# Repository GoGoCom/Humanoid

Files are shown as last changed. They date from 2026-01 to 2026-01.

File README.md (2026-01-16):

# Humanoid

## Introduction

I built a humanoid robot using the ESP32. For robot control, I used the ESP32's BLE or WiFi functions. I utilized PLEN's motion data to capture the robot's movement data.

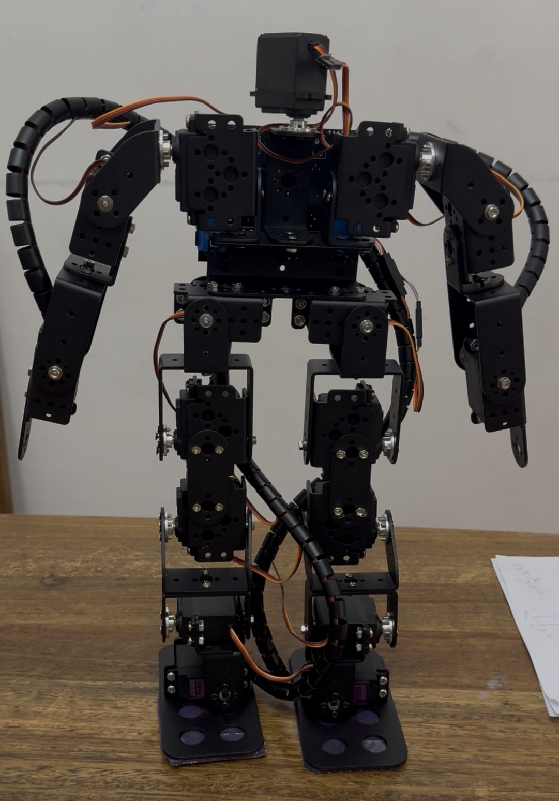
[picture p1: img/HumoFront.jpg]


## Control in webPage using ESP32's BLE

After connecting to the robot via BLE on a web browser on a laptop or PC, you can directly operate the 16 joints or open a data file for a specific continuous movement and make it move. The movement file is borrowed from PLEN-Project( https://github.com/plenprojectcompany ) and can be converted for use, and you can also create movements directly using PLEN's [motion-editor](https://plen.jp/playground/motion-editor/).

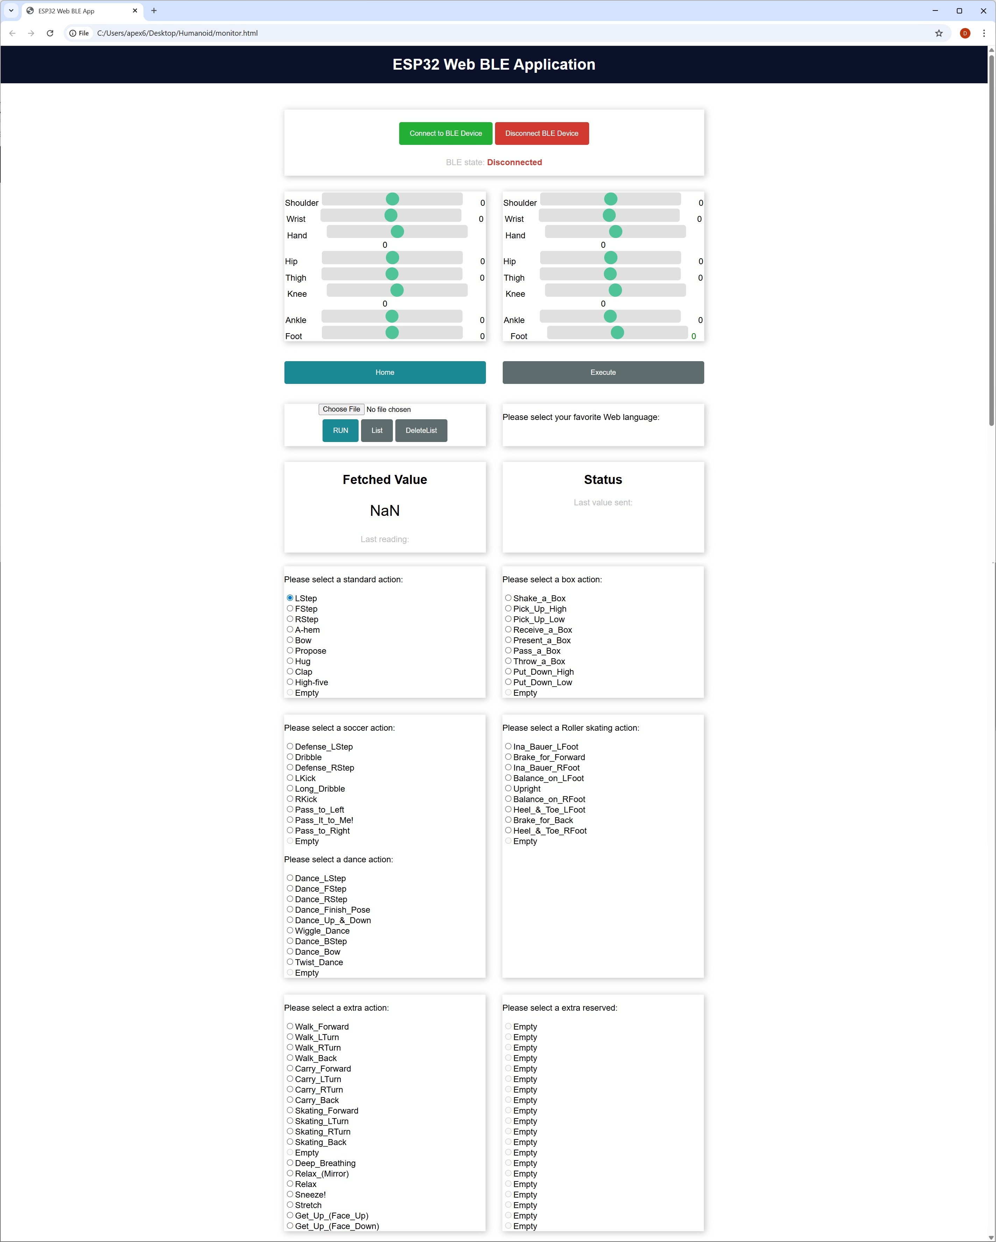
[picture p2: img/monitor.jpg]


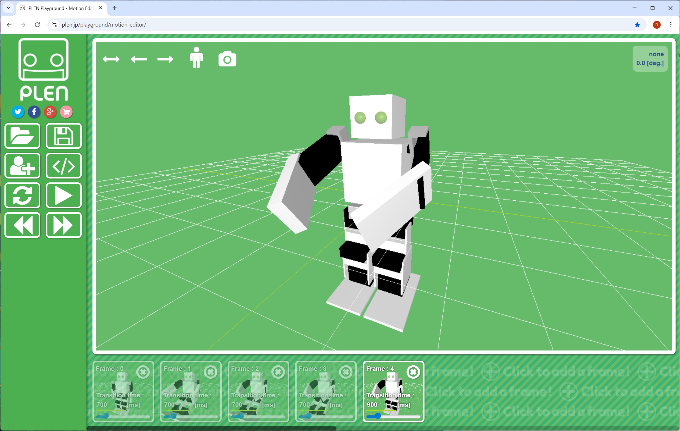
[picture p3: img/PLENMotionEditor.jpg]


## Blynk Tools

[Blynk](https://www.blynk.io/) is an excellent platform for solving IoT problems.It is the most powerful tool when you want to control something on the Internet, whether it is on mobile or PC.
By defining the required streams in the Blynk.Console and connecting them to components, you can exchange data over the network.
You must first sign up on https://blynk.cloud/dashboard/login  before you can use it.

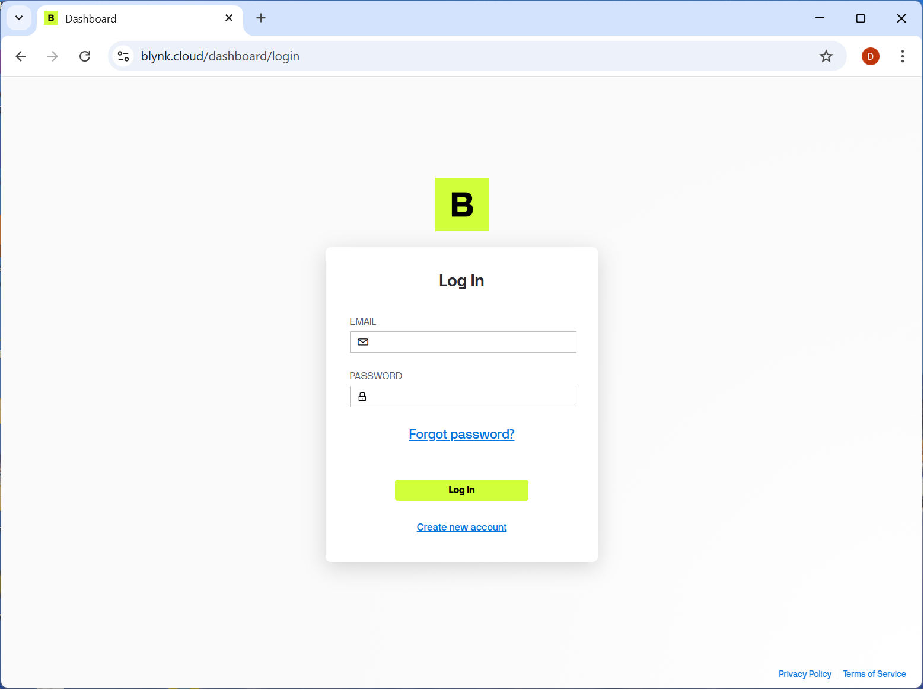
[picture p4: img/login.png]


After defining the device and setting up the development template through the Blynk console, find out the following three values and enter them at the beginning of the source code: BLYNK TEMPLATE ID, BLYNK TEMPLATE_NAME, and BLYNK AUTHTOKEN.


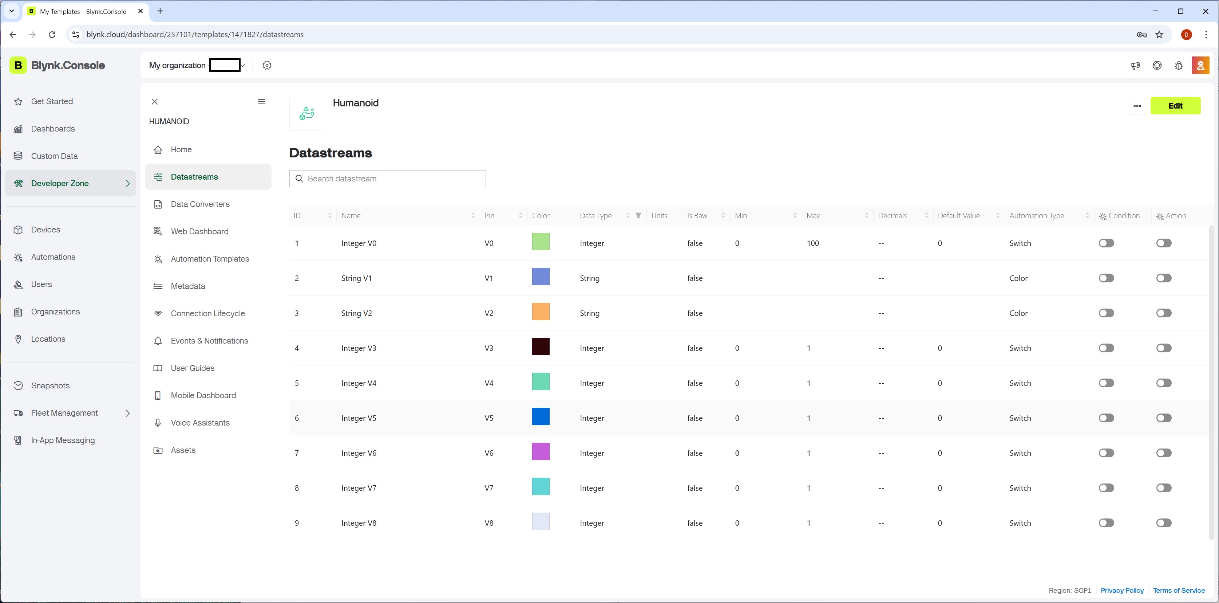
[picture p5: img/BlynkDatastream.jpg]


| define |
|-|
|#define BLYNK_TEMPLATE_ID  "XMgt6fqp4aXvb" |
|#define BLYNK_TEMPLATE_NAME  "Humanoid" |
|#define BLYNK_AUTH_TOKEN  "0f0ffASdldldleefeeXXiCNCvQT3Ff3H" |

### Blynk App / Display

## Library
| Library | version | description |
|-|-|-|
| Blynk | 1.3.2 | IoT |
| ESP8266 and ESP32 OLED driver foe SSSD1306 | 4.6.2 | display |
| ArduinoJson | 7.4.2 | motion datat parsing  |
| ESP32Servo | 3.0.9 | Servo motor  |

## Tool
| Tool | version | description |
|-|-|-|
| Autodesk Eagle | 9.6.2 | hardware |
| Arduino IDE | 2.3.7 | software |

## Acknowledgments

I would like to thank to every one, specially PLEN project team and Rui Santos of RandomNerdTutorials for their contributions.

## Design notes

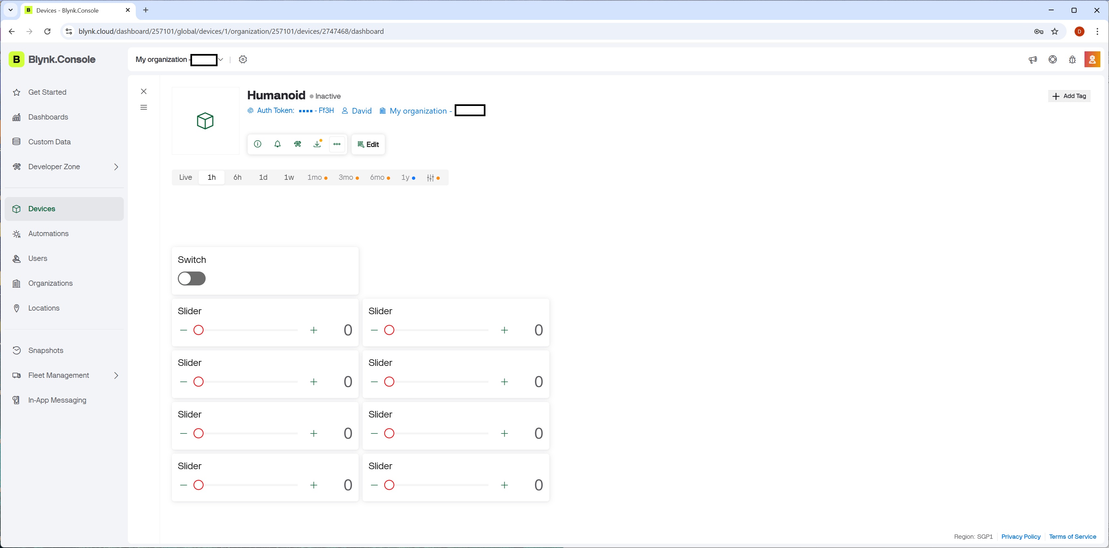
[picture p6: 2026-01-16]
img/device.jpg

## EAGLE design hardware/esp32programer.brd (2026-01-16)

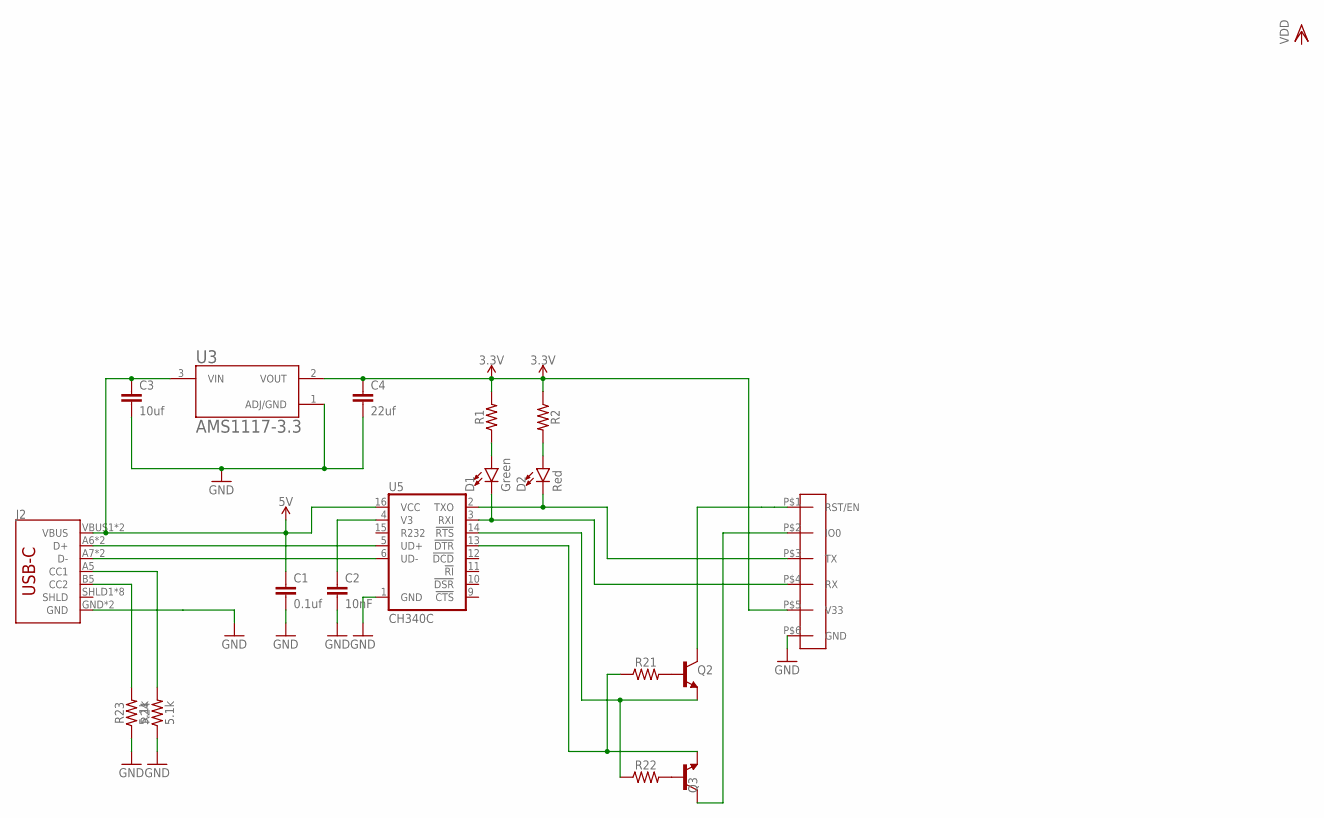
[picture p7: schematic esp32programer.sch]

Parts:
C1: 0.1uf; 0805
C2: 10nF; 0805
C3: 10uf; 0805
C4: 22uf; 0805
D1: Green; LED-0805
D2: Red; LED-0805
J2: USB_C16PIN; USB-C-16P
Q2, Q3: TRANSISTOR_BJT_NPN-SOT-23-BEC; SOT-23
R1, R2, R21, R22: 0805
R23, R24: 5.1k; 0805
U3: AMS1117-3.3; SOT229P700X180-4N
U5: CH340C; SO016
U$6: USBCOUT; 6PINS

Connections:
3.3V: C4.1, R1.2, R2.1, U3.2 (VOUT), U$6.P$5 (V33)
5V: C1.1, C3.1, J2.VBUS1 (VBUS), J2.VBUS2 (VBUS), U3.3 (VIN), U5.16 (VCC)
!DTR: Q3.2 (E), R21.1, U5.13 (!DTR)
CC2: J2.B5 (CC2), R23.2
D+: J2.A6 (D+), J2.B6 (D+), U5.5 (UD+)
D-: J2.A7 (D-), J2.B7 (D-), U5.6 (UD-)
GND: C1.2, C2.2, C3.2, C4.2, J2.GND, J2.GND2 (GND), R23.1, R24.1, U3.1 (ADJ/GND), U5.1 (GND), U$6.P$6 (GND)
unnamed: D1.C, U5.3 (RXI), U$6.P$4 (RX)
unnamed: C2.1, U5.4 (V3)
unnamed: D1.A, R1.1
unnamed: D2.A, R2.2
unnamed: Q2.3 (C), U$6.P$1 (RST/EN)
unnamed: Q3.3 (C), U$6.P$2 (IO0)
unnamed: Q2.2 (E), R22.1, U5.14 (!RTS)
unnamed: Q2.1 (B), R21.2
unnamed: Q3.1 (B), R22.2
unnamed: J2.A5 (CC1), R24.2
RXI: D2.C, U5.2 (TXO), U$6.P$3 (TX)

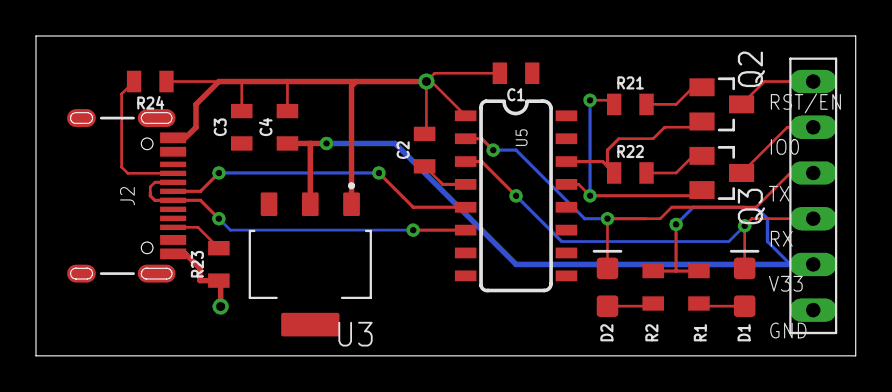
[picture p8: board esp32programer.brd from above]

Board: 2 copper layers, 45.5 x 17.8 mm, 18 parts (0 on the bottom side), 18 nets.

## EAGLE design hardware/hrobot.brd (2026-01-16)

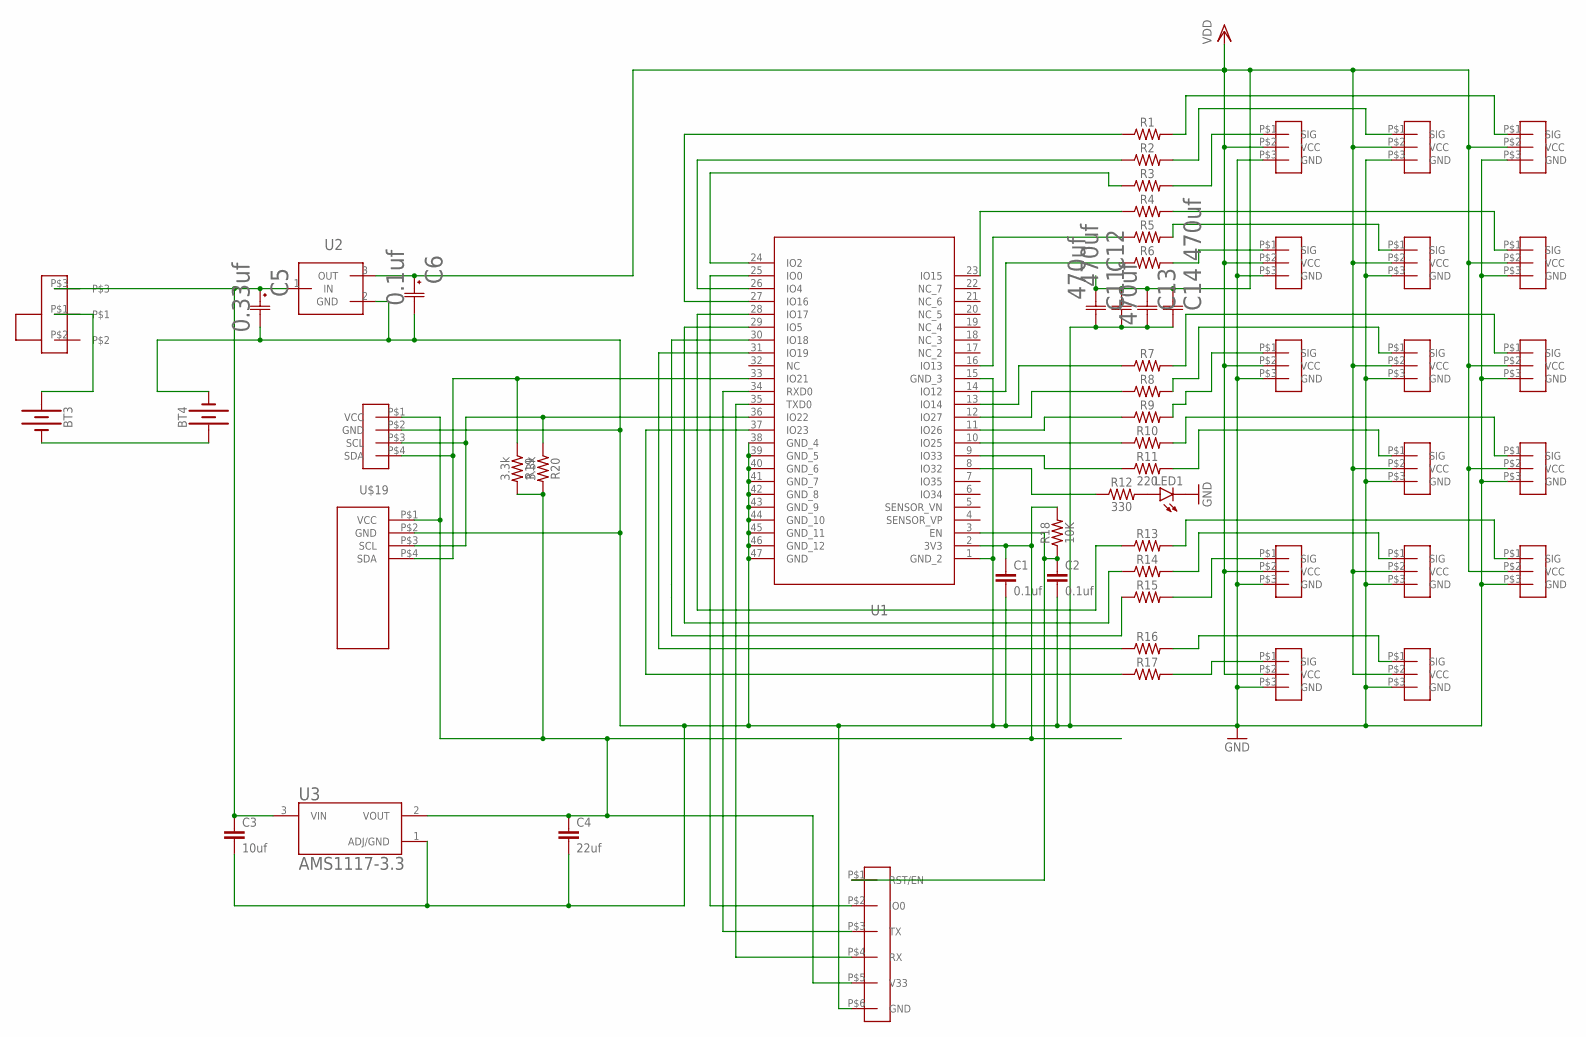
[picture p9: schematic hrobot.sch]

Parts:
BT3, BT4: BATTERY-18650; BATTERY_18650-HOLDER
C1, C2: 0.1uf; 0805
C3: 10uf; 0805
C4: 22uf; 0805
C5: 0.33uf; CAP_UWF_4X5P4_NCH
C6: 0.1uf; CAP_UZE_4X3P9_NCH
C11, C12, C13, C14: 470uf; CAP_J-V_8X10P5_RUB
LED1: LEDSML0805; SML0805
R1, R2, R3, R4, R5, R6, R7, R8, R9, R10, R13, R14, R15, R16, R17: 0805
R11: 220; 0805
R12: 330; 0805
R18: 10K; 0805
R19, R20: 3.3k; 0805
U1: ESP32-WROOM-32E_(4MB)ESP32�WROOM�32E_EXP; ESP32�WROOM�32E_EXP
U2: L7806; L7805FOOT
U3: AMS1117-3.3; SOT229P700X180-4N
U$1, U$2, U$3, U$5, U$6, U$7, U$8, U$9, U$10, U$11, U$12, U$13, U$14, U$15, U$16, U$17: SERVO; 3PINS
U$18: OLEDVCC; OLEPINS
U$19: GYRO; 4PINS
U$20: PWR3PINS
U$23: USBCOUT; 6PINS

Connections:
3V3: C1.1, C4.1, R18.2, R19.2, R20.2, U1.2 (3V3), U3.2 (VOUT), U$18.P$1 (VCC), U$19.P$1 (VCC), U$23.P$5 (V33)
GND: BT4.GND@1 (-), C1.2, C2.2, C3.2, C4.2, C5.2, C6.2, C11.2, C12.2, C13.2, C14.2, LED1.C, U1.1 (GND_2), U1.15 (GND_3), U1.38 (GND_4), U1.39 (GND_5), U1.40 (GND_6), U1.41 (GND_7), U1.42 (GND_8), U1.43 (GND_9), U1.44 (GND_10), U1.45 (GND_11), U1.46 (GND_12), U1.47 (GND), U2.2 (GND), U3.1 (ADJ/GND), U$1.P$3 (GND), U$2.P$3 (GND), U$3.P$3 (GND), U$5.P$3 (GND), U$6.P$3 (GND), U$7.P$3 (GND), U$8.P$3 (GND), U$9.P$3 (GND), U$10.P$3 (GND), U$11.P$3 (GND), U$12.P$3 (GND), U$13.P$3 (GND), U$14.P$3 (GND), U$15.P$3 (GND), U$16.P$3 (GND), U$17.P$3 (GND), U$18.P$2 (GND), U$19.P$2 (GND), U$23.P$6 (GND)
unnamed: BT3.GND@1 (-), BT4.PWR@1 (+)
unnamed: BT3.PWR@1 (+), U$20.P$1
unnamed: R3.2, U$1.P$1 (SIG)
unnamed: R2.2, U$7.P$1 (SIG)
unnamed: R1.2, U$13.P$1 (SIG)
unnamed: R6.2, U$2.P$1 (SIG)
unnamed: R5.2, U$8.P$1 (SIG)
unnamed: R4.2, U$14.P$1 (SIG)
unnamed: R9.2, U$3.P$1 (SIG)
unnamed: R8.2, U$9.P$1 (SIG)
unnamed: R7.2, U$15.P$1 (SIG)
unnamed: LED1.A, R12.2
unnamed: R11.2, U$10.P$1 (SIG)
unnamed: R10.2, U$16.P$1 (SIG)
unnamed: R15.2, U$5.P$1 (SIG)
unnamed: R14.2, U$11.P$1 (SIG)
unnamed: R13.2, U$17.P$1 (SIG)
unnamed: R17.2, U$6.P$1 (SIG)
unnamed: R16.2, U$12.P$1 (SIG)
unnamed: C3.1, C5.1, U2.1 (IN), U3.3 (VIN), U$20.P$3
unnamed: R16.1, U1.31 (IO19)
unnamed: R1.1, U1.27 (IO16)
unnamed: R2.1, U1.26 (IO4)
unnamed: C2.1, R18.1, U1.3 (EN), U$23.P$1 (RST/EN)
unnamed: R4.1, U1.23 (IO15)
unnamed: R5.1, U1.16 (IO13)
unnamed: R6.1, U1.14 (IO12)
unnamed: R17.1, U1.37 (IO23)
unnamed: R14.1, U1.29 (IO5)
unnamed: R15.1, U1.30 (IO18)
unnamed: R13.1, U1.28 (IO17)
unnamed: R19.1, U1.33 (IO21), U$18.P$4 (SDA), U$19.P$4 (SDA)
unnamed: R11.1, U1.9 (IO33)
unnamed: R10.1, U1.10 (IO25)
unnamed: R9.1, U1.11 (IO26)
unnamed: R8.1, U1.12 (IO27)
unnamed: R7.1, U1.13 (IO14)
unnamed: R20.1, U1.36 (IO22), U$18.P$3 (SCL), U$19.P$3 (SCL)
unnamed: R12.1, U1.8 (IO32)
unnamed: R3.1, U1.24 (IO2)
unnamed: U1.35 (TXD0), U$23.P$4 (RX)
unnamed: U1.34 (RXD0), U$23.P$3 (TX)
unnamed: U1.25 (IO0), U$23.P$2 (IO0)
VDD: C6.1, C11.1, C12.1, C13.1, C14.1, U2.3 (OUT), U$1.P$2 (VCC), U$2.P$2 (VCC), U$3.P$2 (VCC), U$5.P$2 (VCC), U$6.P$2 (VCC), U$7.P$2 (VCC), U$8.P$2 (VCC), U$9.P$2 (VCC), U$10.P$2 (VCC), U$11.P$2 (VCC), U$12.P$2 (VCC), U$13.P$2 (VCC), U$14.P$2 (VCC), U$15.P$2 (VCC), U$16.P$2 (VCC), U$17.P$2 (VCC)

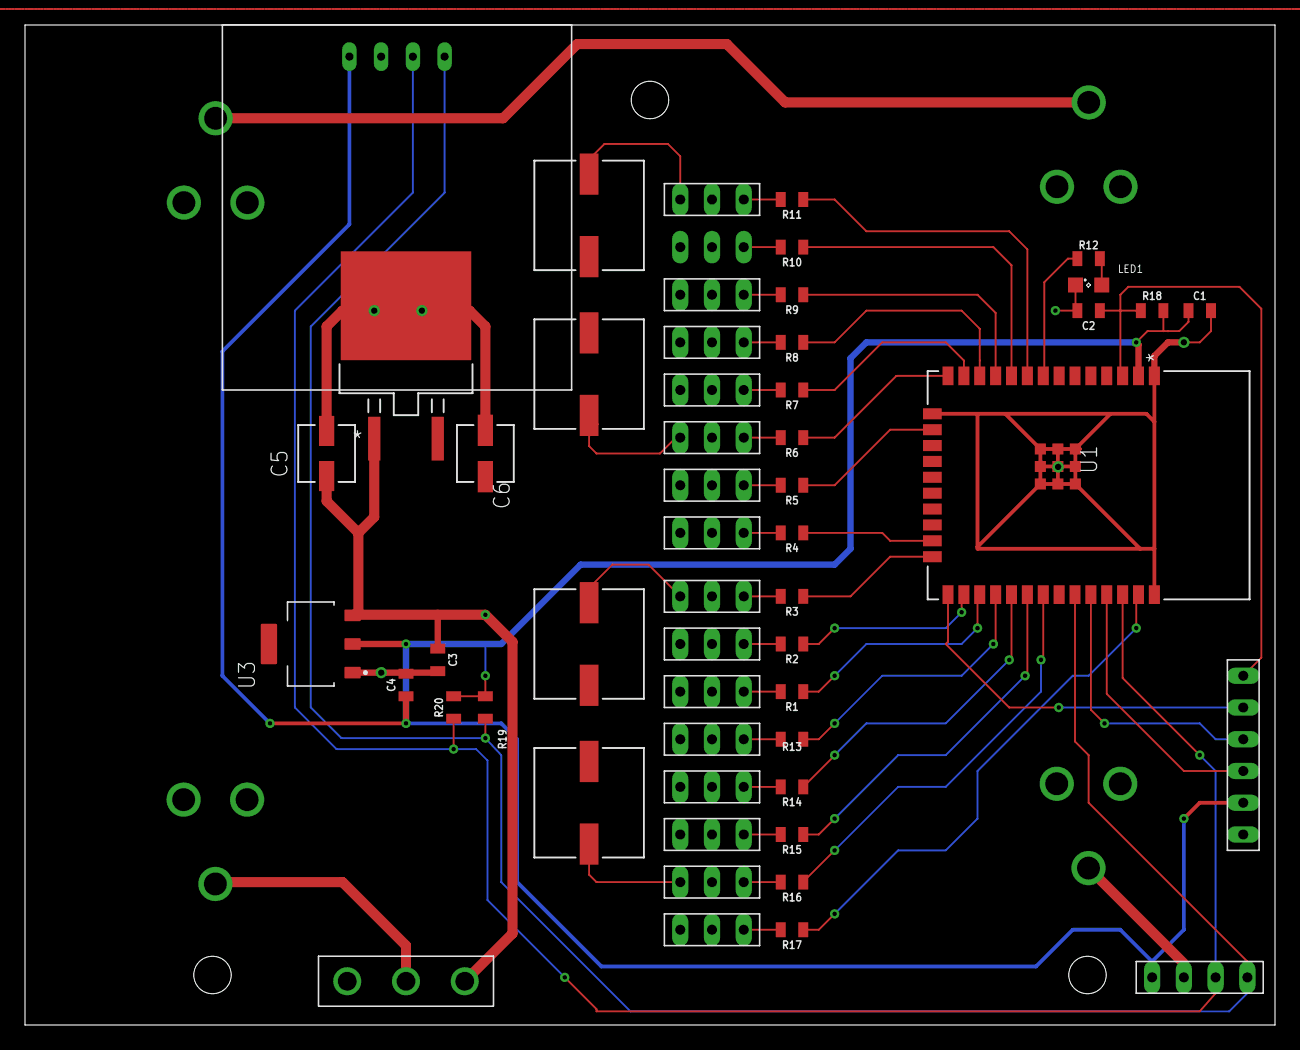
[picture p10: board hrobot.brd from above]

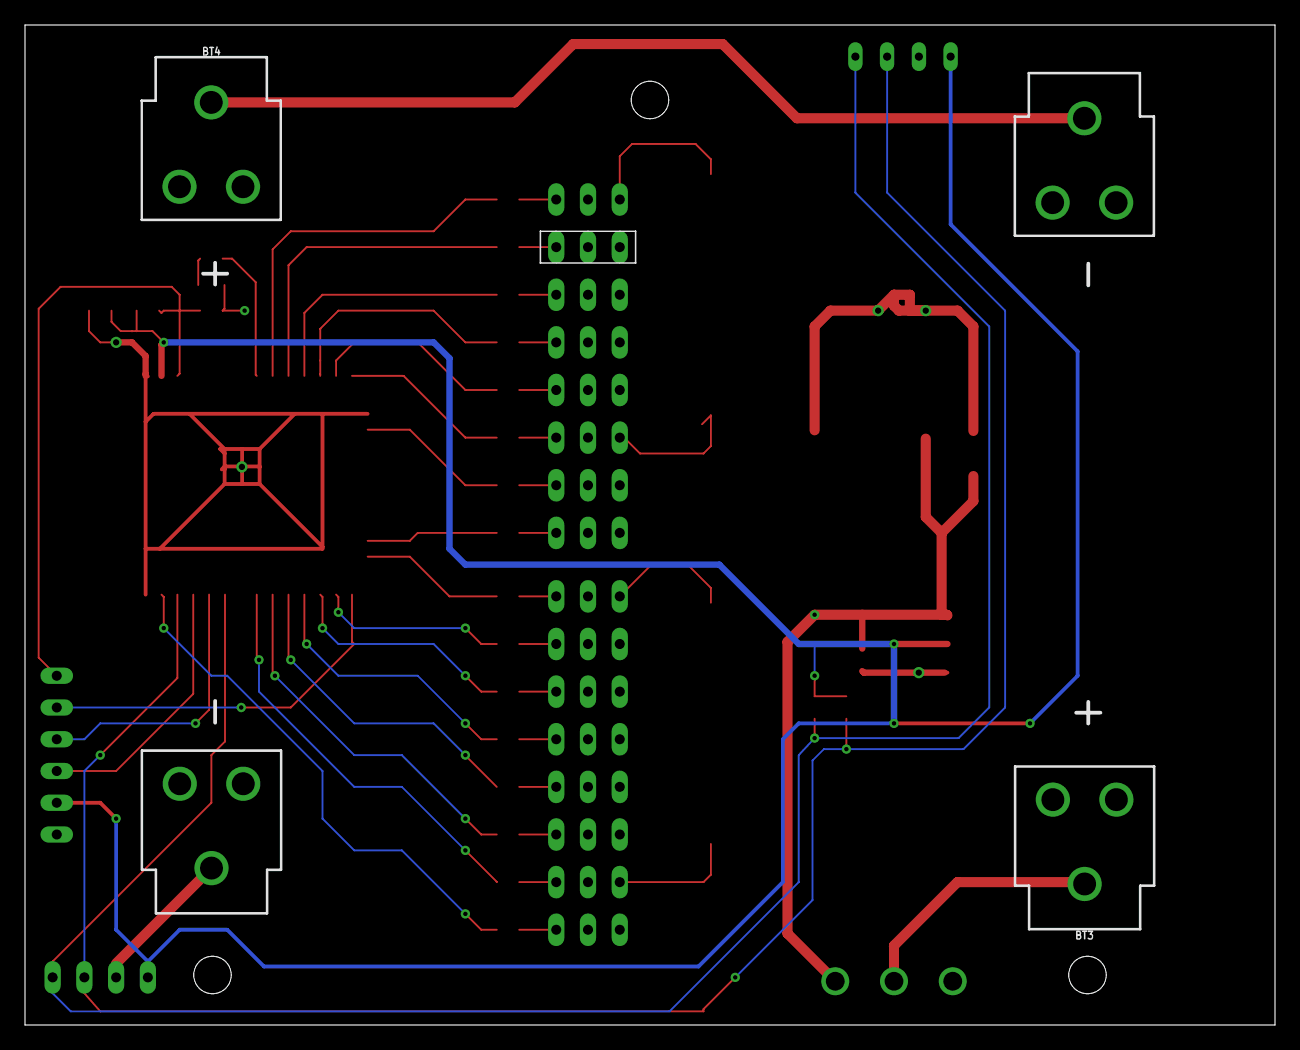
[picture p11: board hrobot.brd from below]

Board: 2 copper layers, 100.0 x 80.0 mm, 56 parts (3 on the bottom side), 46 nets.

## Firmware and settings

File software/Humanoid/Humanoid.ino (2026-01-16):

/**

   Create by David Lee/ Gogocom
   January/2025
   
   The MIT License (MIT)

*/
#define BLYNK_PRINT Serial

/* Fill in information from Blynk Device Info here */
#define BLYNK_TEMPLATE_ID "TMPL6hhhhhh" // your own
#define BLYNK_TEMPLATE_NAME "Humanoid"
#define BLYNK_AUTH_TOKEN "fLaAtyhlrthklrtkhlrtkhrtl;khrl;" // your own

//deserialize a JSON document with ArduinoJson.
#include <ArduinoJson.h>
#include <string.h>

// For a WiFi connection and Blynk
#include <WiFi.h>
#include <WiFiClient.h>
#include <BlynkSimpleEsp32.h>

#include <BLEDevice.h>
#include <BLEServer.h>
#include <BLEUtils.h>
#include <BLE2902.h>

// Include the correct display library
#include <ESP32Servo.h>

// For a connection via I2C using the Arduino Wire include:
#include <Wire.h>               // Only needed for Arduino 1.6.5 and earlier
#include "SSD1306Wire.h"        // legacy: #include "SSD1306.h"

// SPIFFFS for writing or reading a temporary json file.
#include <FS.h>
#include <SPIFFS.h>

/* You only need to format SPIFFS the first time you run a
   test or else use the SPIFFS plugin to create a partition
   https://github.com/me-no-dev/arduino-esp32fs-plugin */
#define FORMAT_SPIFFS_IF_FAILED true



// Optionally include custom images
#include "images.h"

//#define debug

#define LED_ON   HIGH
#define LED_OFF  LOW

#define BLYNK_RED       "#D3435C"
#define BLYNK_GREEN     "#23C48E"
#define BLYNK_DARK_BLUE "#5F7CD8"
#define BLYNK_BLUE      "#04C0F8"
#define BLYNK_WHITE     "#FFFFFF"
#define BLYNK_YELLOW    "#ED9D00"

#define TEST      1
#define WAKING    0
#define BiKiBiKi  1

#define ActionMax 20
#define FramesMax 64

// Your WiFi credentials.
// Set password to "" for open networks.
char* ssid         = "COREANHOUSE";
char* password     = "COREAN000";


enum {
  Right, Left, BothS, BothC
};

enum {
  Shoulder, Elbow, Wrist, Hip, Thigh, Knee, Ankle, Foot 
} ;



//Head 32
struct act {
  int mode ;
  int which;
  int degree;
} ;

struct BehaviorLoop {
    int first;
    int last;
    int count;
};

struct BehaviorBody {
    int index;
    int musle[2][8];
    int tdelay;
};

struct Behavior {
  int count;
  struct BehaviorBody actions[ActionMax];
  int Number;
  const char *Name;
};

struct BehaviorExtend {
  int count;
  struct BehaviorLoop Loop[5];
  struct BehaviorBody actions[ActionMax];
  int Number;
  const char *Name;
};

struct body {
  int pin;
  int offset;
  int initial;
  int min;
  int max;
} RobotBody[2][8] = {
  //Shoulder,               Elbow, (+35, -35)        Wrist,                Hip,                 Thigh,  (-10,+10)        Knee,(+45, -45)        Ankle,                Foot 
//   { { 2, -1, 0,-90, +90 },{ 4, +1,  0, -125, +55 },{16, +1, 0,-90, +90 },{17, +1, 0,-90, +90 },{ 5, +1, 0, -85, +95},{18, -1, 0, -135, +45 },{19, -1, 0, -85, +95 },{23, +1, 0,-90, +90 }},  // right
//   { {33, -1, 0,-90, +90 },{25, +1,  0, -55, +125 },{26, +1, 0,-90, +90 },{27, +1, 0,-90, +90 },{14, +1, 0,-95, +85 },{12, -1, 0, -45, +135 },{13, -1, 0, -95, +85 },{15, +1, 0,-90, +90 }}   // left
   { { 2, -1, 0,-90, +90 },{ 4, +1,  0, -125, +55 },{16, +1, 0,-90, +90 },{17, +1, 0,-90, +90 },{ 5, +1, 0, -45, +135},{18, -1, 0, -58, +122 },{19, -1, 0, -45, +135 },{23, +1, 0,-90, +90 }},  // right
   { {33, -1, 0,-90, +90 },{25, +1,  0, -55, +125 },{26, +1, 0,-90, +90 },{27, +1, 0,-90, +90 },{14, +1, 0,-135, +45 },{12, -1, 0, -122, +58 },{13, -1, 0, -135, +45 },{15, +1, 0,-90, +90 }}   // left
};


  // JSON input string for conversion
const char *jsonDevice = "  {      \
    \"right_thigh_yaw\"      : [0,-1], \
    \"right_shoulder_pitch\" : [0, 0], \
    \"right_shoulder_roll\"  : [0, 1], \
    \"right_elbow_roll\"     : [0, 2], \
    \"right_thigh_roll\"     : [0, 3], \
    \"right_thigh_pitch\"    : [0, 4], \
    \"right_knee_pitch\"     : [0, 5], \
    \"right_foot_pitch\"     : [0, 6], \
    \"right_foot_roll\"      : [0, 7], \
     \"left_thigh_yaw\"      : [1,-1], \
    \"left_shoulder_pitch\"  : [1, 0], \
    \"left_shoulder_roll\"   : [1, 1], \
    \"left_elbow_roll\"      : [1, 2], \
    \"left_thigh_roll\"      : [1, 3], \
    \"left_thigh_pitch\"     : [1, 4], \
    \"left_knee_pitch\"      : [1, 5], \
    \"left_foot_pitch\"      : [1, 6], \
    \"left_foot_roll\"       : [1, 7]  \
    }";

struct BehaviorExtend Frame =
 {
  0,
  {
    {0,0,0},
    {0,0,0}
  },
  {
    { 
      0,
      {
        {0,0,0,0,0,0,0,0 },
        {0,0,0,0,0,0,0,0 }
      },
      0
    },
    {
      1,
      {
        {0,0,0,0,0,0,0,0 },
        {0,0,0,0,0,0,0,0 }
      },
      0
    }
  },
  100,
  "anme"
};

const struct Behavior Frames[] = {
{
 11,
 { {
     0,
     {
       {0,0,0,0,0,0,0,0 },
       {0,0,0,0,0,0,0,0 }
     },
     100
   },{
     1,
     {
       {-114,0,0,50,0,0,0,-157 },
       {-83,-110,0,-64,0,0,0,-159 }
     },
     380
   },{
     2,
     {
       {199,110,142,50,0,0,0,-165 },
       {282,-110,86,-134,268,-918,-266,-129 }
     },
     360
   },{
     3,
     {
       {199,150,142,50,0,0,24,-155 },
       {282,-110,86,-134,-380,-788,-266,-129 }
     },
     340
   },{
     4,
     {
       {199,150,142,50,0,0,24,-145 },
       {282,-110,86,-134,-380,-788,-266,-129 }
     },
     340
   },{
     5,
     {
       {-349,92,55,50,-55,423,285,-175 },
       {-474,-110,-74,-134,346,-866,21,-129 }
     },
     140
   },{
     6,
     {
       {-610,22,52,65,4,423,285,-162 },
       {-422,-190,-132,-128,711,-240,-214,10 }
     },
     180
   },{
     7,
     {
       {-610,22,52,65,4,423,285,-158 },
       {-422,-190,-132,-128,711,-240,-214,10 }
     },
     480
   },{
     8,
     {
       {-377,148,237,50,-229,579,322,-158 },
       {-422,-190,-132,-83,466,-853,252,10 }
     },
     480
   },{
     9,
     {
       {199,148,142,50,-57,0,0,-135 },
       {282,-42,125,-51,268,-475,-110,-129 }
     },
     540
   },{
     10,
     {
       {0,0,0,0,0,0,0,0 },
       {0,0,0,0,0,0,0,0 }
     },
     360
   },
 },
 23,
 "LKick" ,
},{
 16,
 { {
     0,
     {
       {0,0,0,0,0,0,0,0 },
       {0,0,0,0,0,0,0,0 }
     },
     100
   },{
     1,
     {
       {0,-9,-21,20,0,0,0,-10 },
       {-10,9,21,30,0,0,0,0 }
     },
     200
   },{
     2,
     {
       {0,21,-31,150,-268,605,294,140 },
       {0,-21,31,120,-130,0,-110,140 }
     },
     200
   },{
     3,
     {
       {185,51,-29,140,-535,512,27,102 },
       {142,-31,19,140,-120,0,-130,105 }
     },
     110
   },{
     4,
     {
       {185,-9,-39,-50,-325,432,177,-58 },
       {142,-41,29,-50,-240,-90,-360,-85 }
     },
     130
   },{
     5,
     {
       {0,21,31,-120,130,0,110,-140 },
       {0,-21,-31,-150,268,-605,-294,-140 }
     },
     180
   },{
     6,
     {
       {-142,31,19,-140,120,0,130,-105 },
       {-185,-51,-29,-140,535,-512,-27,-102 }
     },
     100
   },{
     7,
     {
       {-142,41,29,50,240,90,360,85 },
       {-185,9,-39,50,325,-432,-177,58 }
     },
     120
   },{
     8,
     {
       {0,21,-31,150,-268,605,294,140 },
       {0,-21,31,120,-130,0,-110,140 }
     },
     210
   },{
     9,
     {
       {185,51,-29,140,-535,512,27,102 },
       {142,-31,19,140,-120,0,-130,105 }
     },
     130
   },{
     10,
     {
       {185,-9,-39,-50,-325,432,177,-58 },
       {142,-41,29,-50,-240,-90,-360,-85 }
     },
     150
   },{
     11,
     {
       {0,21,31,-120,130,0,110,-140 },
       {0,-21,-31,-150,268,-605,-294,-140 }
     },
     240
   },{
     12,
     {
       {-142,31,19,-140,120,0,130,-105 },
       {-185,-51,-29,-140,535,-512,-27,-102 }
     },
     160
   },{
     13,
     {
       {-142,41,29,50,240,90,360,85 },
       {-185,9,-39,50,325,-432,-177,58 }
     },
     180
   },{
     14,
     {
       {0,1,-79,80,-108,245,84,80 },
       {0,-21,-31,40,0,0,0,80 }
     },
     180
   },{
     15,
     {
       {0,0,0,0,0,0,0,0 },
       {0,0,0,0,0,0,0,0 }
     },
     240
   },
 },
 24,
 "Long Dribble" ,
},{
 11,
 { {
     0,
     {
       {0,0,0,0,0,0,0,0 },
       {0,0,0,0,0,0,0,0 }
     },
     100
   },{
     1,
     {
       {83,110,0,64,0,0,0,159 },
       {114,0,0,0,0,0,0,157 }
     },
     380
   },{
     2,
     {
       {-282,110,-86,134,-268,918,266,129 },
       {-199,-110,-142,0,0,0,0,165 }
     },
     360
   },{
     3,
     {
       {-282,110,-86,134,380,788,266,129 },
       {-199,-150,-142,0,0,0,-24,155 }
     },
     340
   },{
     4,
     {
       {-282,110,-86,134,380,788,266,129 },
       {-199,-150,-142,0,0,0,-24,145 }
     },
     340
   },{
     5,
     {
       {474,110,74,134,-346,866,-21,129 },
       {349,-92,-55,0,-4,-423,-285,175 }
     },
     140
   },{
     6,
     {
       {422,190,132,128,-711,240,214,-10 },
       {610,-22,-52,0,0,-579,-322,162 }
     },
     180
   },{
     7,
     {
       {422,190,132,128,-711,240,214,-10 },
       {610,-22,-52,0,0,-579,-322,158 }
     },
     480
   },{
     8,
     {
       {422,190,132,83,-466,853,-252,-10 },
       {377,-148,-237,0,229,-579,-322,158 }
     },
     480
   },{
     9,
     {
       {-282,42,-125,51,-268,475,110,129 },
       {-199,-148,-142,0,57,0,0,135 }
     },
     540
   },{
     10,
     {
       {0,0,0,0,0,0,0,0 },
       {0,0,0,0,0,0,0,0 }
     },
     360
   },
 },
 25,
 "RKick" ,
},{
 15,
 { {
     0,
     {
       {0,0,0,0,0,0,0,0 },
       {0,0,0,0,0,0,0,0 }
     },
     100
   },{
     1,
     {
       {0,322,557,0,0,0,0,0 },
       {0,-322,-557,0,0,0,0,0 }
     },
     200
   },{
     2,
     {
       {0,322,557,20,0,0,0,60 },
       {0,-322,-557,20,0,0,0,60 }
     },
     200
   },{
     3,
     {
       {0,322,557,35,-181,354,157,37 },
       {0,-322,-557,39,0,0,13,76 }
     },
     200
   },{
     4,
     {
       {0,322,557,165,-111,214,87,127 },
       {0,-322,-557,39,0,0,13,46 }
     },
     200
   },{
     5,
     {
       {0,322,557,159,-178,302,155,97 },
       {0,-322,-557,19,90,-127,-50,-60 }
     },
     200
   },{
     6,
     {
       {0,322,557,38,-90,127,50,60 },
       {0,-322,-557,-38,90,-127,-50,-60 }
     },
     200
   },{
     7,
     {
       {0,627,557,38,-522,948,500,60 },
       {0,-627,-557,-38,522,-866,-435,-60 }
     },
     400
   },{
     8,
     {
       {0,322,557,38,-90,127,50,60 },
       {0,-322,-557,-38,90,-127,-50,-60 }
     },
     400
   },{
     9,
     {
       {0,628,557,38,-522,948,500,60 },
       {0,-627,-557,-38,522,-866,-435,-60 }
     },
     400
   },{
     10,
     {
       {0,322,557,38,-90,127,50,60 },
       {0,-322,-557,-38,90,-127,-50,-60 }
     },
     400
   },{
     11,
     {
       {0,322,557,-85,-86,127,50,-80 },
       {0,-322,-557,-182,50,-16,45,-204 }
     },
     200
   },{
     12,
     {
       {0,322,557,-39,-86,127,50,-57 },
       {0,-322,-557,-39,214,-408,-194,-97 }
     },
     200
   },{
     13,
     {
       {0,322,557,0,0,0,0,0 },
       {0,-322,-557,0,0,0,0,0 }
     },
     200
   },{
     14,
     {
       {0,0,0,0,0,0,0,0 },
       {0,0,0,0,0,0,0,0 }
     },
     200
   },
 },
 32,
 "Dance RStep" ,
},{
 7,
 { {
     0,
     {
       {0,0,0,0,0,0,0,0 },
       {0,0,0,0,0,0,0,0 }
     },
     100
   },{
     1,
     {
       {0,322,557,0,0,0,0,0 },
       {0,-322,-557,0,0,0,0,0 }
     },
     600
   },{
     2,
     {
       {0,322,557,0,0,0,0,0 },
       {0,-322,-557,0,0,0,0,0 }
     },
     600
   },{
     3,
     {
       {0,322,557,7,0,0,0,-24 },
       {0,-774,647,2,0,0,0,-5 }
     },
     1000
   },{
     4,
     {
       {0,322,557,216,0,0,0,194 },
       {0,-643,569,196,0,0,0,189 }
     },
     1000
   },{
     5,
     {
       {0,322,557,216,0,0,0,194 },
       {0,-643,569,196,0,0,0,189 }
     },
     1600
   },{
     6,
     {
       {0,0,0,0,0,0,0,0 },
       {0,0,0,0,0,0,0,0 }
     },
     1000
   },
 },
 33,
 "Dance Finish Pose" ,
},{
 9,
 { {
     0,
     {
       {0,0,0,0,0,0,0,0 },
       {0,0,0,0,0,0,0,0 }
     },
     100
   },{
     1,
     {
       {0,322,557,0,-217,620,403,0 },
       {0,-322,-557,0,217,-620,-403,0 }
     },
     600
   },{
     2,
     {
       {0,0,0,0,0,0,0,0 },
       {0,0,0,0,0,0,0,0 }
     },
     600
   },{
     3,
     {
       {0,322,557,0,-217,620,403,0 },
       {0,-322,-557,0,217,-620,-403,0 }
     },
     600
   },{
     4,
     {
       {0,0,0,0,0,0,0,0 },
       {0,0,0,0,0,0,0,0 }
     },
     600
   },{
     5,
     {
       {636,322,557,0,-217,620,403,0 },
       {569,-322,-557,0,217,-620,-403,0 }
     },
     600
   },{
     6,
     {
       {0,0,0,0,0,0,0,0 },
       {0,0,0,0,0,0,0,0 }
     },
     600
   },{
     7,
     {
       {-569,322,557,0,-217,620,403,0 },
       {-636,-322,-557,0,217,-620,-403,0 }
     },
     600
   },{
     8,
     {
       {0,0,0,0,0,0,0,0 },
       {0,0,0,0,0,0,0,0 }
     },
     600
   },
 },
 34,
 "Dance Up & Down" ,
},{
 20,
 { {
     0,
     {
       {0,0,0,0,0,0,0,0 },
       {0,0,0,0,0,0,0,0 }
     },
     100
   },{
     1,
     {
       {0,322,557,-116,0,0,0,-94 },
       {0,-322,-557,-116,0,0,0,-94 }
     },
     600
   },{
     2,
     {
       {0,322,557,116,0,0,0,94 },
       {0,-322,-557,116,0,0,0,94 }
     },
     600
   },{
     3,
     {
       {0,322,557,-116,0,0,0,-94 },
       {0,-322,-557,-116,0,0,0,-94 }
     },
     600
   },{
     4,
     {
       {0,322,557,116,0,0,0,94 },
       {0,-322,-557,116,0,0,0,94 }
     },
     600
   },{
     5,
     {
       {0,322,557,-116,0,0,0,-94 },
       {0,-322,-557,-116,0,0,0,-94 }
     },
     600
   },{
     6,
     {
       {0,322,557,116,0,0,0,94 },
       {0,-322,-557,116,0,0,0,94 }
     },
     600
   },{
     7,
     {
       {0,322,557,-116,0,0,0,-94 },
       {0,-322,-557,-116,0,0,0,-94 }
     },
     600
   },{
     8,
     {
       {0,322,557,116,0,0,0,94 },
       {0,-322,-557,116,0,0,0,94 }
     },
     600
   },{
     9,
     {
       {0,322,557,-116,0,0,0,-94 },
       {0,-322,-557,-116,0,0,0,-94 }
     },
     600
   },{
     10,
     {
       {0,322,557,116,0,0,0,94 },
       {0,-643,569,116,0,0,0,94 }
     },
     600
   },{
     11,
     {
       {0,322,557,-99,157,0,131,-84 },
       {0,-322,-557,-109,-177,0,-120,-103 }
     },
     580
   },{
     12,
     {
       {0,322,557,-99,-139,0,-95,-84 },
       {0,-322,-557,-109,119,0,81,-81 }
     },
     580
   },{
     13,
     {
       {0,322,557,110,-139,0,-95,125 },
       {0,-322,-557,114,119,0,81,101 }
     },
     580
   },{
     14,
     {
       {0,322,557,110,157,0,131,125 },
       {0,-322,-557,114,-177,0,-120,101 }
     },
     580
   },{
     15,
     {
       {0,324,-56,-99,157,0,131,-84 },
       {0,-747,308,-109,-177,0,-120,-103 }
     },
     580
   },{
     16,
     {
       {0,768,-317,-99,-139,0,-95,-84 },
       {0,-278,99,-109,119,0,81,-81 }
     },
     580
   },{
     17,
     {
       {0,324,-56,110,-139,0,-95,125 },
       {0,-747,308,114,119,0,81,101 }
     },
     580
   },{
     18,
     {
       {0,768,-317,110,157,0,131,125 },
       {0,-278,99,114,-177,0,-120,101 }
     },
     580
   },{
     19,
     {
       {0,0,0,0,0,0,0,0 },
       {0,0,0,0,0,0,0,0 }
     },
     600
   },
 },
 35,
 "Wiggle Dance" ,
},{
 12,
 { {
     0,
     {
       {0,0,0,0,0,0,0,0 },
       {0,0,0,0,0,0,0,0 }
     },
     100
   },{
     1,
     {
       {0,0,0,0,0,0,0,0 },
       {0,0,0,0,0,0,0,0 }
     },
     440
   },{
     2,
     {
       {0,0,0,-100,0,0,0,-100 },
       {0,0,0,-84,152,-388,-199,-84 }
     },
     220
   },{
     3,
     {
       {147,0,0,-100,-126,128,27,-100 },
       {202,0,0,-84,-100,-116,-223,-84 }
     },
     400
   },{
     4,
     {
       {147,628,556,-100,-555,882,359,-100 },
       {202,-625,-555,-84,562,-939,-415,-84 }
     },
     400
   },{
     5,
     {
       {147,0,0,-100,-126,128,27,-100 },
       {202,0,0,-84,-11,-116,-152,-84 }
     },
     400
   },{
     6,
     {
       {147,627,558,-100,-555,882,359,-100 },
       {202,-625,-557,-84,562,-939,-415,-84 }
     },
     400
   },{
     7,
     {
       {147,0,0,-100,-126,128,27,-100 },
       {202,0,0,-84,-100,-116,-223,-84 }
     },
     400
   },{
     8,
     {
       {69,0,0,100,-373,340,-17,122 },
       {72,0,0,84,0,0,0,84 }
     },
     200
   },{
     9,
     {
       {0,0,0,100,-102,298,159,150 },
       {0,0,0,84,0,0,0,94 }
     },
     200
   },{
     10,
     {
       {0,0,0,100,0,0,0,100 },
       {0,0,0,84,0,0,0,84 }
     },
     200
   },{
     11,
     {
       {0,0,0,0,0,0,0,0 },
       {0,0,0,0,0,0,0,0 }
     },
     440
   },
 },
 36,
 "Dance BStep" ,
},{
 4,
 { {
     0,
     {
       {0,0,0,0,0,0,0,0 },
       {0,0,0,0,0,0,0,0 }
     },
     100
   },{
     1,
     {
       {-517,177,516,0,-403,0,-130,0 },
       {-560,-136,-516,0,403,0,130,0 }
     },
     1000
   },{
     2,
     {
       {-517,177,516,0,-403,0,-130,0 },
       {-560,-136,-516,0,403,0,130,0 }
     },
     3060
   },{
     3,
     {
       {0,0,0,0,0,0,0,0 },
       {0,0,0,0,0,0,0,0 }
     },
     1140
   },
 },
 37,
 "Dance Bow" ,
},{
 10,
 { {
     0,
     {
       {0,0,0,0,0,0,0,0 },
       {0,0,0,0,0,0,0,0 }
     },
     100
   },{
     1,
     {
       {0,322,557,0,-217,620,403,0 },
       {0,-322,-557,0,217,-620,-403,0 }
     },
     600
   },{
     2,
     {
       {0,0,0,0,0,0,0,0 },
       {0,0,0,0,0,0,0,0 }
     },
     600
   },{
     3,
     {
       {0,322,557,0,-217,620,403,0 },
       {0,-322,-557,0,217,-620,-403,0 }
     },
     600
   },{
     4,
     {
       {0,0,0,0,0,0,0,0 },
       {0,0,0,0,0,0,0,0 }
     },
     600
   },{
     5,
     {
       {-374,92,-4,0,-217,620,403,0 },
       {797,-92,-4,0,217,-620,-403,0 }
     },
     600
   },{
     6,
     {
       {-795,95,4,0,-217,620,403,0 },
       {371,-89,4,0,217,-620,-403,0 }
     },
     600
   },{
     7,
     {
       {-374,92,-4,0,-217,620,403,0 },
       {797,-92,-4,0,217,-620,-403,0 }
     },
     600
   },{
     8,
     {
       {-795,95,4,0,-217,620,403,0 },
       {371,-89,4,0,217,-620,-403,0 }
     },
     600
   },{
     9,
     {
       {0,0,0,0,0,0,0,0 },
       {0,0,0,0,0,0,0,0 }
     },
     600
   },
 },
 38,
 "Twist Dance" ,
},{
 6,
 { {
     0,
     {
       {0,0,0,0,0,0,0,0 },
       {0,0,0,0,0,0,0,0 }
     },
     100
   },{
     1,
     {
       {443,100,488,-130,-50,308,284,-160 },
       {-443,-100,-488,-220,409,-704,-212,-190 }
     },
     980
   },{
     2,
     {
       {443,619,-449,-130,347,464,366,-235 },
       {-424,-523,438,19,624,6,418,-10 }
     },
     1240
   },{
     3,
     {
       {443,619,-449,-130,347,464,366,-235 },
       {-424,-523,438,19,624,6,418,-10 }
     },
     1240
   },{
     4,
     {
       {443,100,488,-130,-50,308,284,-160 },
       {-443,-100,-488,-220,409,-704,-212,-190 }
     },
     980
   },{
     5,
     {
       {0,0,0,0,0,0,0,0 },
       {0,0,0,0,0,0,0,0 }
     },
     600
   },
 },
 40,
 "Ina Bauer LFoot" ,
},{
 2,
 { {
     0,
     {
       {0,0,0,0,0,0,0,0 },
       {0,0,0,0,0,0,0,0 }
     },
     800
   },{
     1,
     {
       {-2,130,255,50,-3,236,182,70 },
       {12,-166,-297,-50,10,-238,-174,-70 }
     },
     660
   },
 },
 41,
 "Brake for Forward" ,
},{
 14,
 { {
     0,
     {
       {0,0,0,0,0,0,0,0 },
       {0,0,0,0,0,0,0,0 }
     },
     100
   },{
     1,
     {
       {0,111,119,140,0,0,0,140 },
       {-10,-111,-119,140,0,0,0,140 }
     },
     160
   },{
     2,
     {
       {0,111,119,150,-268,605,294,140 },
       {0,-111,-119,120,0,0,0,140 }
     },
     220
   },{
     3,
     {
       {185,111,119,140,-385,402,27,102 },
       {142,-111,-119,140,0,0,0,105 }
     },
     220
   },{
     4,
     {
       {147,111,119,-140,-255,298,96,-140 },
       {281,-111,-119,-140,15,-165,-227,-140 }
     },
     380
   },{
     5,
     {
       {0,111,119,-120,0,0,0,-140 },
       {0,-111,-119,-150,268,-605,-294,-140 }
     },
     180
   },{
     6,
     {
       {-142,111,119,-140,0,0,0,-105 },
       {-185,-111,-119,-140,385,-402,-27,-102 }
     },
     220
   },{
     7,
     {
       {-281,111,119,1,-15,165,227,1 },
       {-147,-111,-119,1,255,-298,-96,1 }
     },
     360
   },{
     8,
     {
       {-281,111,119,1,-290,823,547,1 },
       {-147,-111,-119,1,625,-819,-229,1 }
     },
     600
   },{
     9,
     {
       {-629,314,27,1,-94,823,547,1 },
       {629,-317,-25,1,412,-819,-229,1 }
     },
     800
   },{
     10,
     {
       {-629,314,27,1,-94,823,547,1 },
       {629,-317,-25,1,412,-819,-229,1 }
     },
     1400
   },{
     11,
     {
       {-281,111,119,140,-15,165,227,140 },
       {-147,-111,-119,140,255,-298,-96,140 }
     },
     800
   },{
     12,
     {
       {0,111,119,150,-268,605,294,140 },
       {0,-111,-119,120,0,0,0,140 }
     },
     200
   },{
     13,
     {
       {0,0,0,0,0,0,0,0 },
       {0,0,0,0,0,0,0,0 }
     },
     580
   },
 },
 5,
 "Propose" ,
},{
 12,
 { {
     0,
     {
       {0,0,0,0,0,0,0,0 },
       {0,0,0,0,0,0,0,0 }
     },
     100
   },{
     1,
     {
       {-570,551,0,0,0,0,0,0 },
       {589,-513,0,0,0,0,0,0 }
     },
     800
   },{
     2,
     {
       {-570,551,0,0,0,0,0,0 },
       {589,-513,0,0,0,0,0,0 }
     },
     400
   },{
     3,
     {
       {-570,309,355,0,0,0,0,0 },
       {570,-309,-355,0,0,0,0,0 }
     },
     800
   },{
     4,
     {
       {-570,309,355,0,0,0,0,0 },
       {570,-309,-355,0,0,0,0,0 }
     },
     800
   },{
     5,
     {
       {-570,309,-33,0,0,0,0,0 },
       {570,-309,-355,0,0,0,0,0 }
     },
     400
   },{
     6,
     {
       {-570,309,520,0,0,0,0,0 },
       {570,-309,-355,0,0,0,0,0 }
     },
     300
   },{
     7,
     {
       {-570,309,-33,0,0,0,0,0 },
       {570,-309,-355,0,0,0,0,0 }
     },
     300
   },{
     8,
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
void loop() {

  if( ConnectResult == 0 ) {
     Blynk.run();
  } 

  if (deviceConnected) {
    txValue++;
  }
  // disconnecting
  if (!deviceConnected && oldDeviceConnected) {
    Serial.println("Device disconnected.");
    delay(500); // give the bluetooth stack the chance to get things ready
    pServer->startAdvertising(); // restart advertising
    Serial.println("Start advertising");
    oldDeviceConnected = deviceConnected;
    txValue = 0;
  }
  // connecting
  if (deviceConnected && !oldDeviceConnected) {
    // do stuff here on connecting
    oldDeviceConnected = deviceConnected;
    Serial.println("Device Connected");

  }

}

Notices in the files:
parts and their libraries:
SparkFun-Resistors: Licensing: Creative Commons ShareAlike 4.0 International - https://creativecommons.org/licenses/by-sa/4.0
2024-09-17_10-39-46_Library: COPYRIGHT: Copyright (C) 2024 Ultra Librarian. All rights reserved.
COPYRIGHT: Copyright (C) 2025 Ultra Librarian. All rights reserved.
